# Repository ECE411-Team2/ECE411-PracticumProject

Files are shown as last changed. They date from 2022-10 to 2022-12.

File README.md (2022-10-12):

# ECE-411-Team-2

Our project planning will be split into practium checkpoints, each with their own focus:
  1. Teams Formed 
  2. Projects Decided 
  3. Project requirements (Product Design Specification - PDS)
  4. Preliminary schematic
  5. Final schematic + preliminary layout
  6. Boards to manufacturing (actual final schematic + final layout)
  7. Demonstrations

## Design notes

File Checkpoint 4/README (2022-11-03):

Checkpoint Outcomes 

By week 5-6
  - First bits of code
  - Parts ordered 
  - Preliminary schematic

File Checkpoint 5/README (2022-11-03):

Checkpoint Outcomes 

By week 6-7
  - Final schematic 
  - Preliminary layout / CAD
  - Most code implemented and prototyped 
  - Project Schedule
  - BOM

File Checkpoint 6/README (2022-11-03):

Checkpoint Outcomes

By week 8: 
  - Design Review 
  - Final Layout/ CAD
  - Send items to EPL for print
  
By week 9: 
  - Assembled board 
  - Tested board
  - Programmed board

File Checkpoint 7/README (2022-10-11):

Checkpoint Outcomes

By week 10:
  - DEMO!
  
Deliverables for Prof
  - Final presentation/ demo 
  - Colab site 
  - CAD and source files 
  - BOM w/ cost

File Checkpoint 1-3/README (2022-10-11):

Checkpoint Outcomes
 
By week 3 
  - Brainstorm 3 project ideas
  - Create collaboration site 
  - Choose tools for communication, coding, schematic layouts, etc. 

By week 4
  - Project requirments (PDS)
  - Block Diagrams 
  - Rough schematics
  - Inital component research 
  - Inital timeline

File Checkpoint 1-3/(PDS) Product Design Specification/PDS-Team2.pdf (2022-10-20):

Practicum Project: Team 2

ECE 411

10/20/22

Project Description Specification

Executive Summary / Concept of Operations

Our device is a calculator that has the basic functions of addition, subtraction, multiplication, and division. It will be able to do these calculations through binary and decimal and hexadecimal. With our kind of classes in computer engineering, we do a lot of work with binary and hexadecimal, so we can use it in our classes. In order to use it, you will use the buttons, and depending on the setting, will need to type it in binary, decimal, or hexadecimal. From there, you hit the equals button and it will output onto the screen the answer.

Brief Market Analysis

We want to target customers that have a need for doing binary, decimal, and hexadecimal calculations. This target group includes, but is not limited to, computer engineering professionals and students. The other products are calculators such as the TI-30XIIS, but how our calculator differs is that it comes with the ability to do basic calculations in hex and binary. Compared to the price of the TI-30XIIS, which on amazon is listed as 13 USD, we can estimate ours to be around 15-20 USD. This can be accredited to our inexpensive processor and other electronic components. We would see our 3D printed parts costing the most.

Requirements

Our calculator must have keys that will reflect the following: integers 0-9, the 4 basic operators, equals to, negative, clear all, on/off, A-F, and a button to alternate between Binary, Hex, and Decimal. The calculator must have the ability to remember the past result, must have a display, must have a delay of less than 1 second after each key press, and must be portable. We would also like to incorporate other functions that a standard calculator has as well. Such as, our calculator should be able to handle decimals and parentheses. Then, we will have a stretch goal for our calculator device that may include exponents, trig calculations, and constants (i.e pi and e).

System Architecture

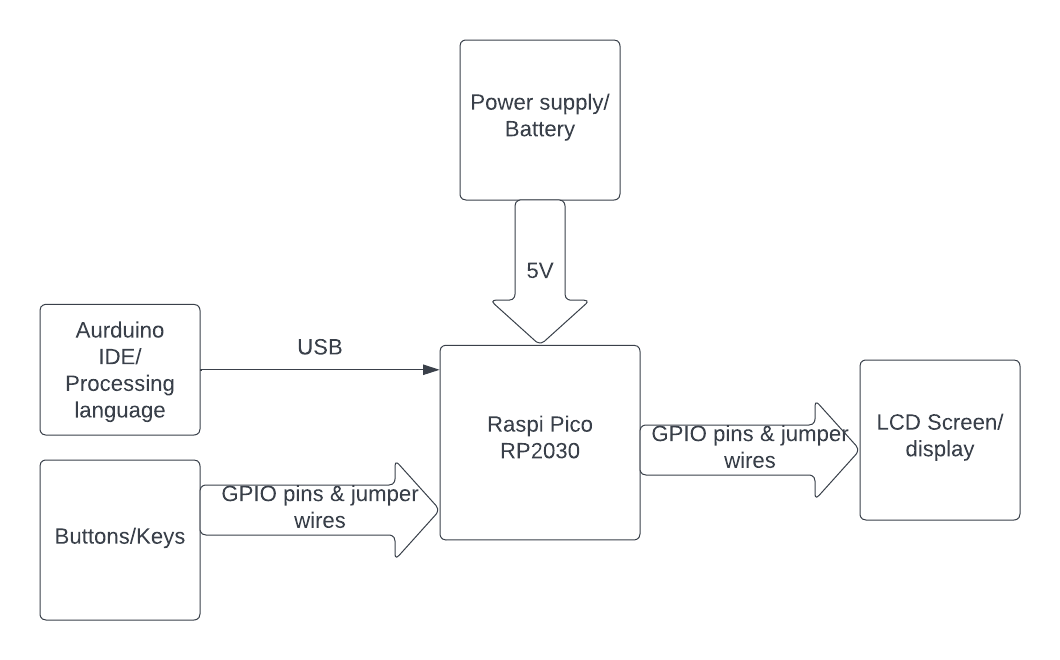
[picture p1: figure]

Design Specification

Sensor:

- Push buttons for each respective key

Processor:

- Raspberry Pi Pico RP2040

Actuator:

- LCD screen

Power:

- 5 Volt battery

Mechanical Design:

- 3D-printed keys for each button
- 3D printed enclosure w/ cutout for LCD screen

Firmware:

- UF2 Bootloader
- Processing language

Development Environment:

- Arduino IDE

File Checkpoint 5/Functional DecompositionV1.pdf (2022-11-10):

Calculator: Level 0

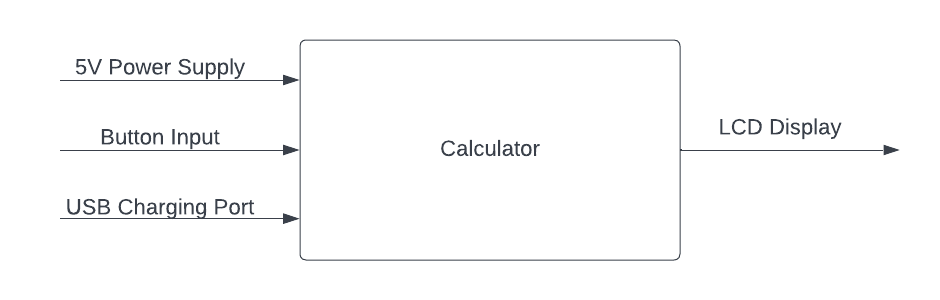
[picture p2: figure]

Module | Calculator
Inputs | Power: 5V DC Button Inputs: Variable Charging Port: USB 5V DC
Outputs | LCD Display: Variable
Functionality | Take input of a mathematical expression and produce a precise calculation. Button input should have user control. LCD display should output the correct calculation to show the user. The calculator can perform basic operations on decimal, hex, and binary numbers.

Calculator: Level 1

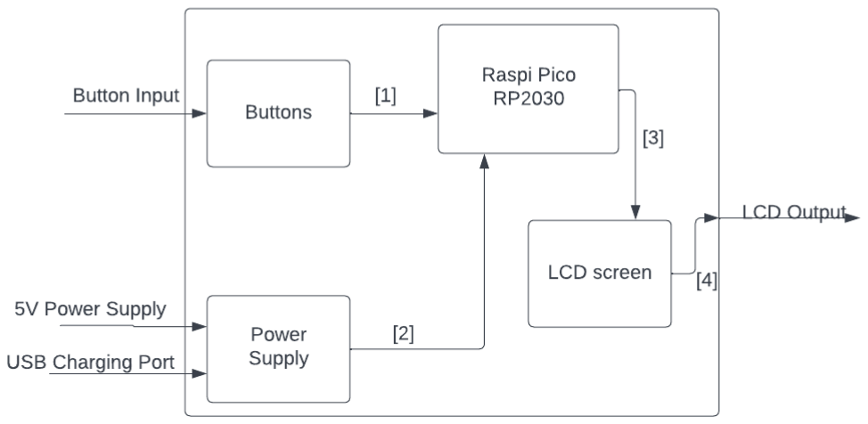
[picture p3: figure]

[1]: GPIO pins
[2]: 5V to power Raspi Pico [3]: I2C data
[4]: LCD Display for user

Raspi Pico RP2030: Level 1

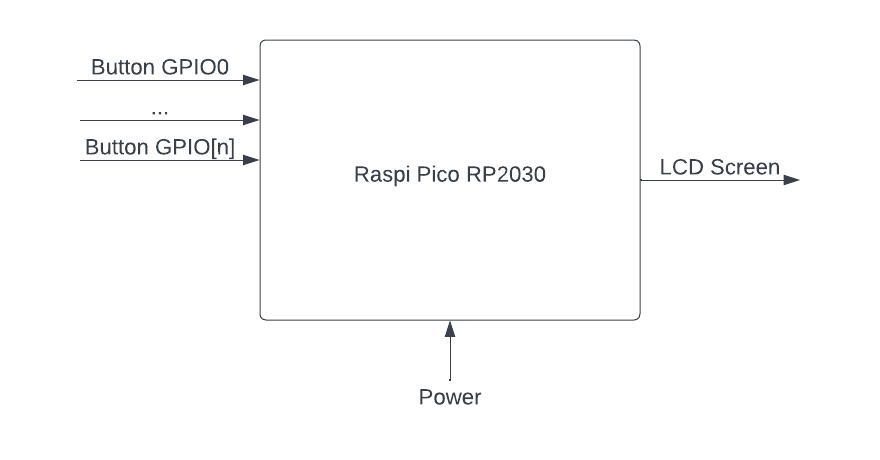
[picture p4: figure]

Module | Raspi Pico RP2030
Inputs | Button GPIO[n] Pins: Tracks I2C data coming in from each button push. Power: 5V supply
Outputs | LCD Screen: I2C data is sent to the LCD screen for display output. The LCD screen is also powered by the Raspi Pico.
Functionality | The Raspi Pico RP2030 serves as the brain of the calculator, processing all incoming information and sending it out to be displayed.

Buttons: Level 1

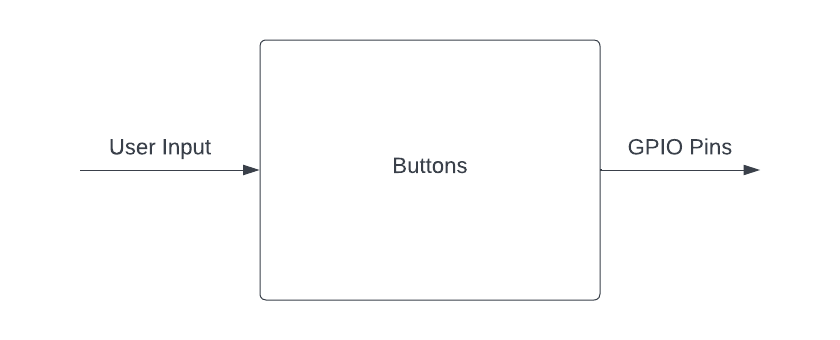
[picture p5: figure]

Module | 25 Buttons
Inputs | User Input: 25 buttons in a 5x5 array, each representing a number, mathematical operation, or turning the device off.
Outputs | GPIO Pins: Connecting to Raspi Pico input pins for processing. Resistors: Each row/column will connect to a ohm resistor (10 total).
Functionality | The user can press any button to input the desired mathematical expression. This will be read and processed by the Raspi Pico.

LCD Screen: Level 1

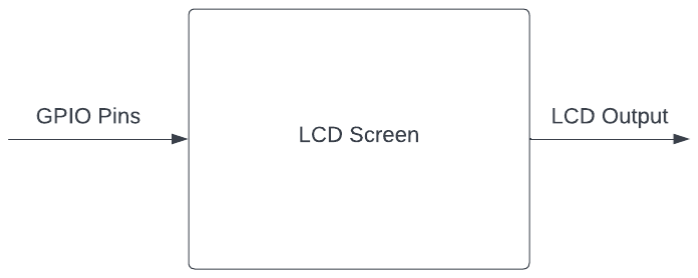
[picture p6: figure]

Module | LCD Screen
Inputs | GPIO Pins: I2C data from the Raspi Pico.
Outputs | LCD Output: LCD display showing the precise calculation of the User’s desired input operation.
Functionality | Will display the information/calculation processed by the Raspi Pico for the user to see.

Power Supply: Level 1

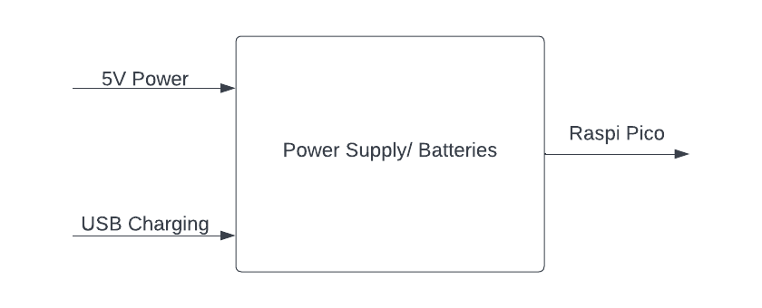
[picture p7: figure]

Module | Power Supply
Inputs | Power: 5V USB Charging: Charge the batteries through a USB input.
Outputs | Raspi Pico: Will supply the Raspi Pico with 5V for necessary function.
Functionality | Supplying the Raspi Pico with DC voltage through a chargeable battery.

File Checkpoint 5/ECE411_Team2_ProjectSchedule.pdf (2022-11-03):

Name | Begin date | End date | Duration
1: Initial Prototype | 10/19/22 | 10/31/22 | 9
1.1 Block diagram | 10/19/22 | 10/20/22 | 2
1.2: Prelim Schematic | 10/20/22 | 10/24/22 | 3
1.3: Prelim Board Layout | 10/25/22 | 10/27/22 | 3
1.4: Skeloton/Prelim Code | 10/26/22 | 10/31/22 | 4
2: CAD Rough Draft | 11/1/22 | 11/16/22 | 12
2.1: Housing Design | 11/1/22 | 11/4/22 | 4
2.2: BOM | 11/3/22 | 11/4/22 | 2
2.3: Final Button Circuitry | 11/4/22 | 11/16/22 | 9
3: Integration and Testing | 11/11/22 | 11/29/22 | 13
3.1: Final Code | 11/11/22 | 11/18/22 | 6
3.2: Print Off Housing and Board | 11/11/22 | 11/21/22 | 7
3.3: Put circuitry In Housing | 11/22/22 | 11/25/22 | 4
3.4: Debugging | 11/11/22 | 11/29/22 | 13
4: Demo Prep | 11/30/22 | 12/9/22 | 8
4.1: Test Plan | 11/30/22 | 12/1/22 | 2
4.2: Presentation and Report Prep | 12/1/22 | 12/8/22 | 6
4.3: Demo | 12/9/22 | 12/9/22 | 1
ECE411 - Team2 Practicum | Nov 2, 2022
Tasks | 2

ECE411 - Team2 Practicum | Nov 2, 2022
Gantt Chart | 3
Name | Begin date | End date | Duration
1: Initial Prototype | 10/19/22 | 10/31/22 | 9.0 day
1.1 Block diagram | 10/19/22 | 10/20/22 | 2.0 day
1.2: Prelim Schematic | 10/20/22 | 10/24/22 | 3.0 day
1.3: Prelim Board Layout | 10/25/22 | 10/27/22 | 3.0 day
1.4: Skeloton/Prelim Code | 10/26/22 | 10/31/22 | 4.0 day
2: CAD Rough Draft | 11/1/22 | 11/16/22 | 12.0 day
2.1: Housing Design | 11/1/22 | 11/4/22 | 4.0 day
2.2: BOM | 11/3/22 | 11/4/22 | 2.0 day
2.3: Final Button Circuitry | 11/4/22 | 11/16/22 | 9.0 day
3: Integration and Testing | 11/11/22 | 11/29/22 | 13.0 day
3.1: Final Code | 11/11/22 | 11/18/22 | 6.0 day
3.2: Print Off Housing and Board | 11/11/22 | 11/21/22 | 7.0 day
3.3: Put circuitry In Housing | 11/22/22 | 11/25/22 | 4.0 day
3.4: Debugging | 11/11/22 | 11/29/22 | 13.0 day
4: Demo Prep | 11/30/22 | 12/9/22 | 8.0 day
4.1: Test Plan | 11/30/22 | 12/1/22 | 2.0 day
4.2: Presentation and Report Prep | 12/1/22 | 12/8/22 | 6.0 day
4.3: Demo | 12/9/22 | 12/9/22 | 1.0 day
October 2022 | November 2022 | December 2022
19 | 20 | 21 | 24 | 25 | 26 | 27 | 28 | 31 | 1 | 2 | 3 | 4 | 7 | 8 | 9 | 10 | 11 | 14 | 15 | 16 | 17 | 18 | 21 | 22 | 23 | 24 | 25 | 28 | 29 | 30 | 1 | 2 | 5 | 6 | 7 | 8

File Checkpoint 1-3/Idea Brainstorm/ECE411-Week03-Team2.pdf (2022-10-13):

Team 2
ECE 411
10/12/22 Week 3
- Photoresistor Car
- Sensor: Photoresistor,
- Actuator: Motor/s
- Processor: Arduino
- Links:
https://www.sciencebuddies.org/science-fair-projects/project-ideas/Robotics_p022/robotics/light-following-robot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 (https://www.sciencebuddies.org/science-fair-projects/project-ideas/Robotics_p022/robotics/light-following-robot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) https://www.instructables.com/Photoresistor-Sensor-With-Arduino-Uno-R3/
A car that will react to a light; driving towards the souce with the help of a couple of photoresistors. There would be 4 motors and an Arduino to power it. However, this would be a little difficult to power as the Arduino can only provide up to 5V.
We desire to do this project as one of our group members mentioned that his brother attempted a similar project during his time in college. With a good foundation brought by that experience, we think this specific take would be attractive yet challenging. The idea of building a car, in itself, is a very fun thing that we think we would find a lot of enjoyment in.
- Calculator (This is what we will go with)
- Sensor: Key/number pad
- Actuator: LCD,
- Processor: Arduino
- Links: https://unimplementedtrap.com/sb116-programmers-calculator Arduino Calculator - Arduino Project Hub (https://create.arduino.cc/projecthub/123samridhgarg/arduino-calculator-bb57c7) This is a traditional calculator with a keypad that allows user input and an LED screen showing the appropriate output. Basic operations would be our first goal but our stretch goal would be to incorporate memory, integrals, and other ways to incorporate complex calculations.
We are very intrigued to see how many features we could add to this. Is it as easy as it seems? As we explore the Arduino library, we want to see how much we can incorporate our own unique spin on a tool that many use on a daily basis.

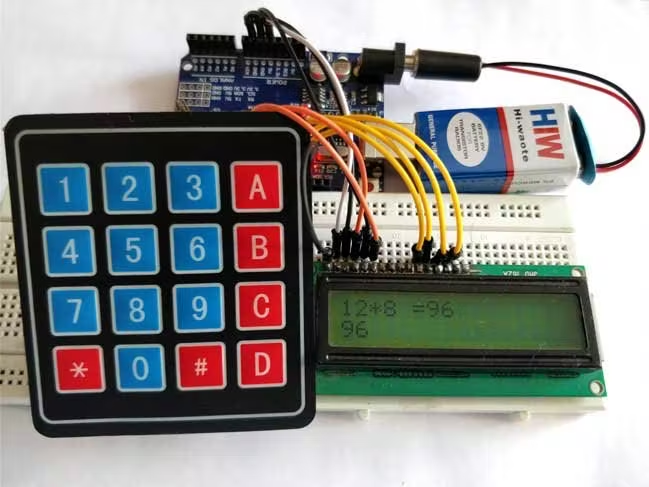
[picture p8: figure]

- Heartbeat sensor
- Sensor: Pulse sensor, potentiometer
- Actuator: LCD, LED
- Processor: Arduino
- Links: Heartbeat Sensor using Arduino (Heart Rate Monitor) (electronicshub.org) (https://www.electronicshub.org/heartbeat-sensor-using-arduino-heart-rate-monitor/) https://create.arduino.cc/projecthub/Ingeimaks/diy-heart-rate-sensor-a96e 89 (https://create.arduino.cc/projecthub/Ingeimaks/diy-heart-rate-sensor-a96e89)
Heart Beat Monitoring Device - Arduino Project Hub (https://create.arduino.cc/projecthub/mohammadsohail0008/heart-beat-monitoring-device-8adf7c)
This device will have a pulse sensor that the user will place their finger on to monitor their heartbeat. The LCD will then display BPM of their heart rate with accuracy. There will be an LED that will turn on, signaling it is reading user input.
This seems to be a very increasing yet difficult project. When researching ideas, we noticed how many people attempt this but there were varying levels of success. There were a lot of issues with accuracy. We are curious to see how accurate we could get this device.

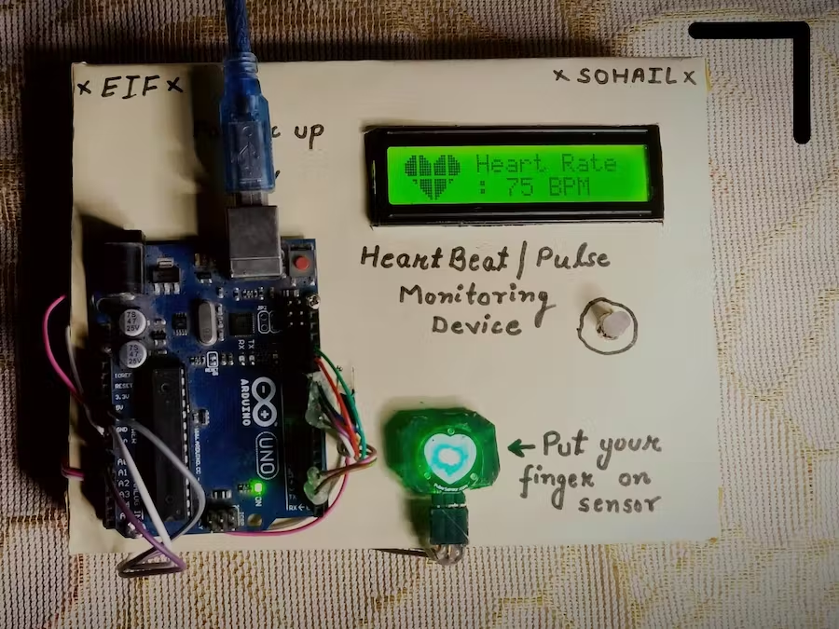
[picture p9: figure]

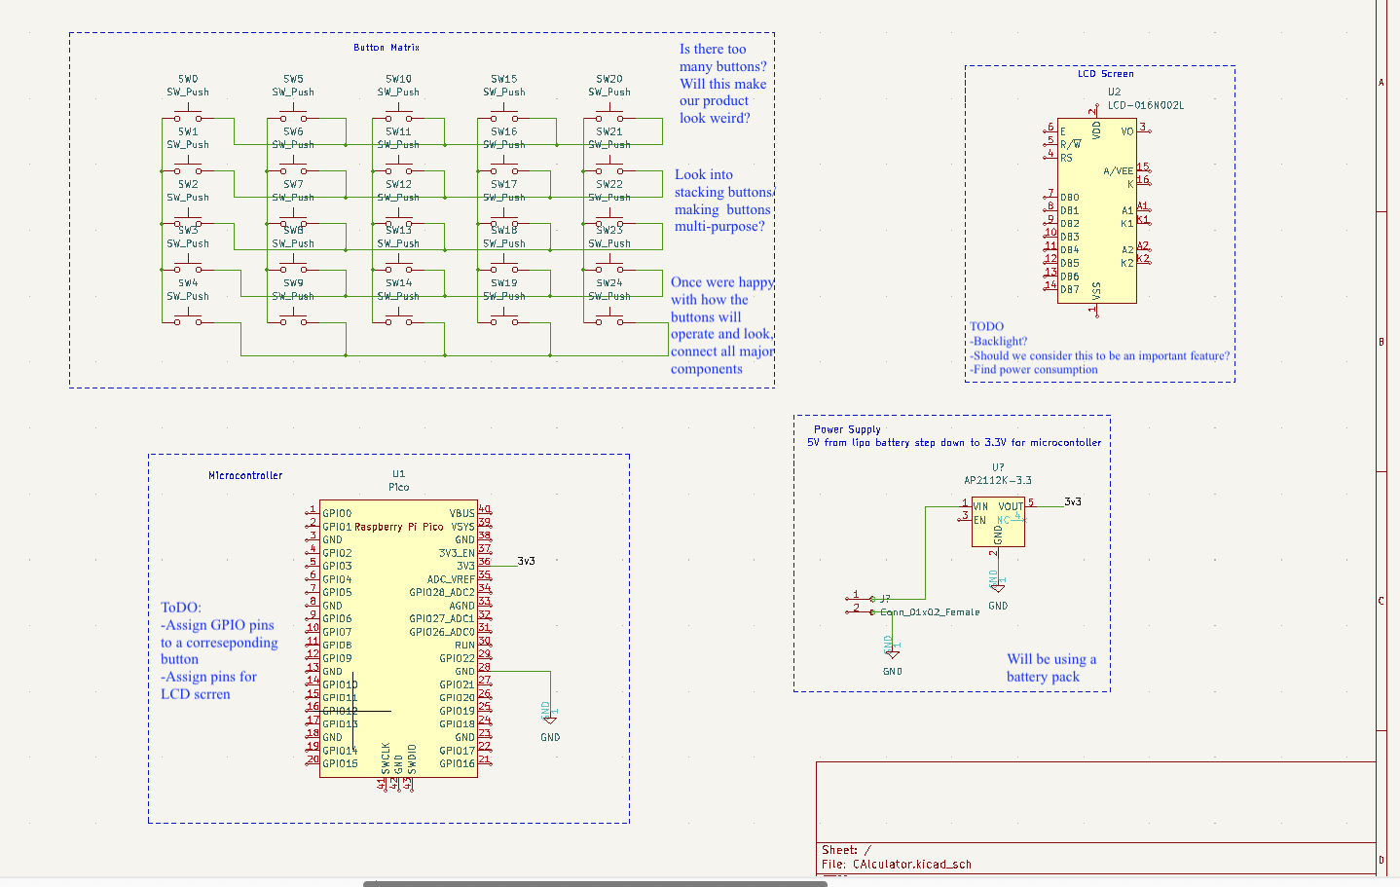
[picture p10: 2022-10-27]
Checkpoint 4/Preliminary Schematic/Calculator.png

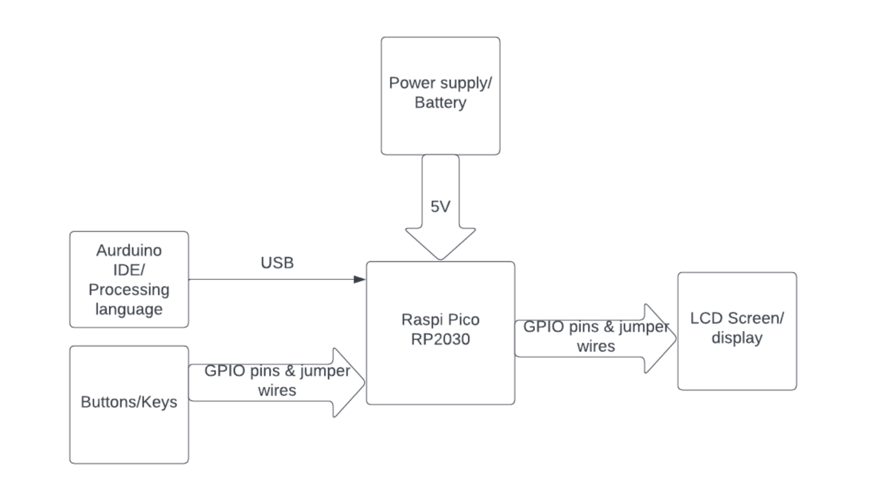
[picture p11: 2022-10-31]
Checkpoint 1-3/Block Diagram 1/Team2_BlockDiagram.png

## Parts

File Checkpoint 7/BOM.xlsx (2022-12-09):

Bill Of Materials for: [TEAM 2]
Last modified: [2022-12-01]
PCB version: [PCB VERSION #2]
BOM revision: [BOM REVISION #2] |  | P/NP | Place/Not Place (components marked NP are not stuffed on the board)
Cnt | Part References | P/NP | Mfg | Mfg PN | Description | Dist | Dist Part Number | Cost Ea. | Cost Total
75 | SW0 to SW24 | P | Chanzon | RA11-BUTTON-SWITCH | Tact Push Button Switch 6x6x 6mm Micro Momentary Tact Switch Terminal Length 3.5mm 2 pin | Amazon | B09R3ZPWJ7 | $0.30 | $22.50
2 | U2 | P | GeeekPi | LCM1602A--SDBTSW-5APWUC | I2C 1602 LCD Display Module 16X2 Character Serial Blue Backlight LCD | Amazon | B07S7PJYM6 | $10.99 | $21.98
4 | U3 | P | MakerFocus | A-9065115 | 4pcs 3.7V Lithium Rechargable Battery JST1.25 Connector 2pin, 852540 3.7V | Amazon | B07CXNQ3ZR | $5.25 | $20.99
4 | U1 | P | Generic | 0C-13694V-0H3320 | Raspberry Pi Pico RP2040 microcontroller | Amazon | B09437S9X4 | $5.50 | $22.21
40 | R1-R10 | P | N/A | N/A | 330Ohm 1/16W, 5% Resistors | EPL | 1206 | $0.04 | $1.60
4 | U0 | NP | Oshpark | N/A | Custom PCB Board | EPL | N/A | $20.57 | $82.30
1 | U4 | NP | Craft Smart | 694300 | Red Silicone Craft Mat | MSPCI | 10694300 | $5.24 | $5.24
1 | U5 | NP | N/A | N/A | Custom 3D Printed Model | EPL | N/A | $7.00 | $7.00
 |  |  |  |  |  |  |  | TOTAL: | $183.82
VERSION INFO
Rev | Date | Notes
1.0r0 | 2022-11-07 | Initial BOM. Not everything chosen yet
2.0r0 | 2022-12-01 | Final BOM

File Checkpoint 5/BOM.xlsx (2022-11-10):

Bill Of Materials for: [TEAM 2]
Last modified: [2022-11-07]
PCB version: [PCB VERSION #1]
BOM revision: [BOM REVISION #1] |  | P/NP | Place/Not Place (components marked NP are not stuffed on the board)
Cnt | Part References | P/NP | Mfg | Mfg PN | Description | Dist | Dist Part Number | Cost Ea. | Cost Total
25 | SW0 to SW24 | P | Chanzon | RA11-BUTTON-SWITCH | Tact Push Button Switch 6x6x 6mm Micro Momentary Tact Switch Terminal Length 3.5mm 2 pin | Amazon | B09R3ZPWJ7 | $0.30 | $6.99
1 | U2 | P | GeeekPi | LCM1602A--SDBTSW-5APWUC | I2C 1602 LCD Display Module 16X2 Character Serial Blue Backlight LCD | Amazon | B07S7PJYM6 | $10.99 | $10.99
4 | U3 | P | MakerFocus | A-9065115 | 4pcs 3.7V Lithium Rechargable Battery JST1.25 Connector 2pin, 852540 3.7V | Amazon | B07CXNQ3ZR | $5.25 | $20.99
4 | U1 | P | Generic | 0C-13694V-0H3320 | Raspberry Pi Pico RP2040 microcontroller | Amazon | B09437S9X4 | $5.50 | $22.21
5 | N/A | NP | N/A | N/A | resistors | N/A | N/A | $0.00 | $0.00
 |  |  |  |  |  |  |  | TOTAL: | $60.02
VERSION INFO
Rev | Date | Notes
1.0r0 | 2020-11-07 | Initial BOM. Not everything chosen yet

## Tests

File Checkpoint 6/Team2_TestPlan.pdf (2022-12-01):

Test Author: Team 2 - Ahliah, Angelo, Bendjy, Ibrahim
Test Case Name: | LCD Display 1 Test | Test ID #: | LCD-01
Description: | Verify the button inputs work by displaying appropriate button inputs. Each button has a number or action associated with it so, when a button is pushed, the corresponding number/action must be displayed on the LCD screen. | Type: | □ white box ✔ black box □ ________

Tester Information
| Name of Tester: | | Date:
| HW/SW Version: | 1.0 | Time:
| Setup: | Verify overall wiring reflects the schematic and LCD screen is OFF, nothing on the screen should be displayed but it must be tied to power.
S T E P | Action | Expected Result | P A S S | F A I L | N / A | Comments
1 | Press the ‘ON’ button | LCD screen turns ON and is blank
2 | Press the ‘1’ button | 1 appears on the top row of screen
3 | Press the ‘2’ button | 12 appears on the top row of screen
4 | Press the ‘3’ button | 123 appears on the top row of screen
5 | Press the ‘4’ button | 1234 appears on the top row of screen
6 | Press the ‘5’ button | 12345 appears on the top row of screen
7 | Press the ‘6’ button | 123456 appears on the top row of screen
8 | Press the ‘7’ button | 1234567 appears on the top row of screen
9 | Press the ‘8’ button | 12345678 appears on the top row of screen
10 | Press the ‘9’ button | 123456789 appears on the top row of screen
11 | Press the ‘0’ button | 1234567890 appears on the top row of screen
12 | Press the ‘CLR’ button | LCD screen is still ON but blank
13 | Press the ‘OFF’ button | LCD screen turns OFF
| Overall test result:

Test Author: Team 2 - Ahliah, Angelo, Bendji, Ibrahim
Test Case Name: | I2C Communication | Test ID #: | I2C-COM-01
Description: | Verify that the I2C bus is communicating with the LCD. Information must be able to be transmitted through the I2C to the LCD and then accurately displayed on the screen. | Type: | □ white box ✔ black box □ ________

Tester Information
| Name of Tester: | Bendjy Faurestal | Date: | 11/30/2022
| HW/SW Version: | 1.0 | Time: | 8:00pm
| Setup: | Have the LCD screen OFF and tied to power, ground, I2C SDA and I2C SCL.
S T E P | Action | Expected Result | P A S S | F A I L | N / A | Comments
1 | Send ‘on’ signal | LCD screen is powered and turned ON with a clear screen | ✔ | | | The display is blank each time it is powered on.
2 | Send value of ‘1’ | LCD screen displays ‘1’ on the top row | ✔
3 | Send value of ‘2’ | LCD screen displays ‘12’ on the top row | ✔
4 | Send ‘off’ signal | LCD screen turns OFF | ✔
| Overall test result: | | ✔

Test Author: Team 2 - Ahliah, Angelo, Bendji, Ibrahim
Test Case Name: | Mathematical Operations Software Test | Test ID #: | Math-01
Description: | Verify that the math functions work properly and that the correct data is displayed in the console with decimal, binary and hex as a result. | Type: | □ white box ✔ black box □ ________

Tester Information
| Name of Tester: | Angelo Maldonado-Liu | Date: | 11/30/2022
| HW/SW Version: | 1.0 | Time: | 6:30pm
| Setup: | Plug Ras-Pi Pico chip into a computer and open the console.
S T E P | Action | Expected Result | P A S S | F A I L | N / A | Comments
1 | Perform ‘15 + 26’ Math operation, then display result | ‘41’ displayed in console | ✔
2 | Change display from last result (41 decimal) to a hex value | ‘29’ displayed in console | ✔
3 | Change display from last result (29 hex) to binary | ‘101001’ displayed in the console | ✔
4 | Perform ‘14 / 6’ math operation, then display result | ‘2’ is displayed in the console | ✔
5 | Perform ‘3 * 18’ math operation, then display result | ‘54’ is displayed in the console | ✔
6 | Perform ‘31 - 9’ math operation, then display result | ‘22’ is displayed in the console | ✔
| Overall test result: | | ✔ | | | Values displayed the expected results in a forever loop. This was due to a coding error within the standard void loop. Incorporating an end to the loop fixed this issue.

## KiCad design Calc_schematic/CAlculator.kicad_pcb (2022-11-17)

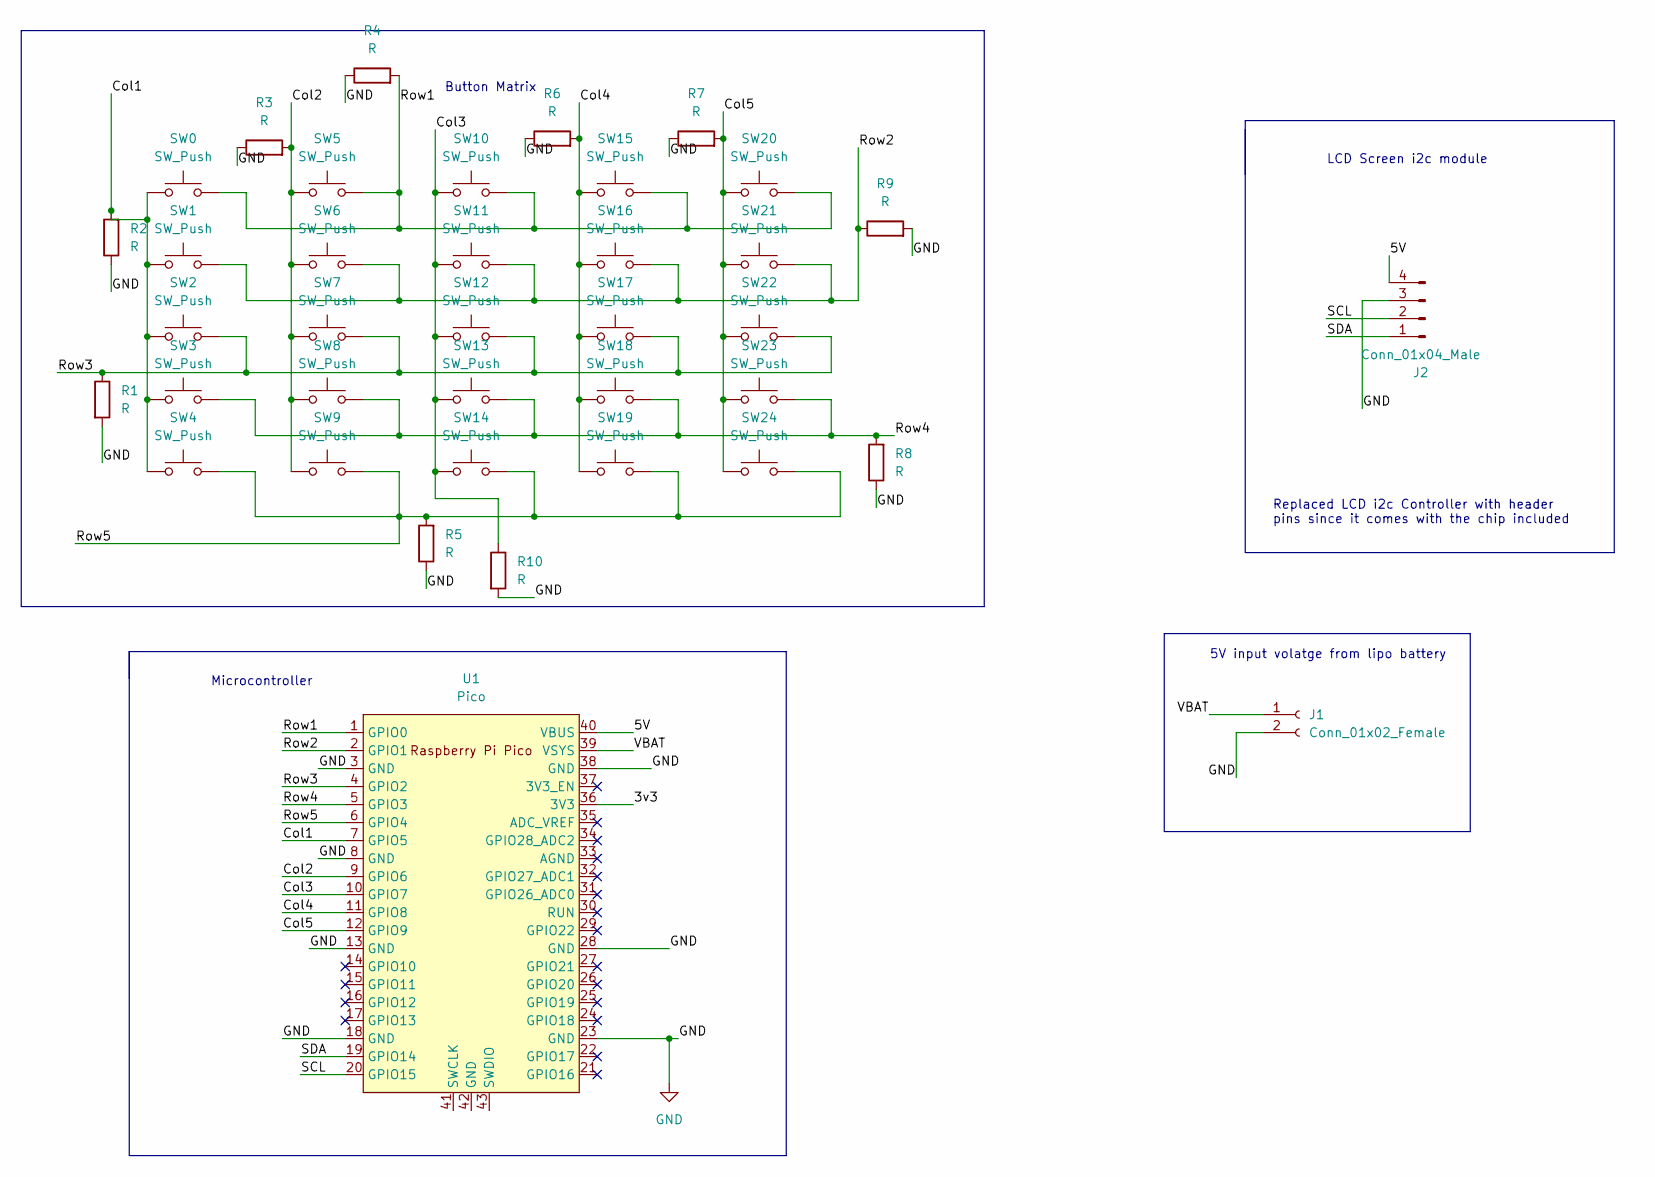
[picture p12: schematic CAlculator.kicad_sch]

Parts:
J1: Conn_01x02_Female; JST_PH_B2B-PH-K_1x02_P2.00mm_Vertical
J2: Conn_01x04_Male; PinHeader_1x04_P2.54mm_Vertical
R1, R2, R3, R4, R5, R6, R7, R8, R9, R10: R; RESC3216X60N
SW0, SW1, SW2, SW3, SW4, SW5, SW6, SW7, SW8, SW9, SW10, SW11, SW12, SW13, SW14, SW15, SW16, SW17, SW18, SW19, SW20, SW21, SW22, SW23, SW24: SW_Push; SW_PUSH_6mm_H5mm
U1: Pico; RPi_Pico_SMD_TH

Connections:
/3v3: U1.36 (3V3)
/5V: J2.4, U1.40 (VBUS)
/Col1: R2.2, SW0.1, SW1.1, SW2.1, SW3.1, SW4.1, U1.7 (GPIO5)
/Col2: R3.2, SW5.1, SW6.1, SW7.1, SW8.1, SW9.1, U1.9 (GPIO6)
/Col3: R10.1, SW10.1, SW11.1, SW12.1, SW13.1, SW14.1, U1.10 (GPIO7)
/Col4: R6.2, SW15.1, SW16.1, SW17.1, SW18.1, SW19.1, U1.11 (GPIO8)
/Col5: R7.2, SW20.1, SW21.1, SW22.1, SW23.1, SW24.1, U1.12 (GPIO9)
/Row1: R4.2, SW0.2, SW5.2, SW10.2, SW15.2, SW20.2, U1.1 (GPIO0)
/Row2: R9.1, SW1.2, SW6.2, SW11.2, SW16.2, SW21.2, U1.2 (GPIO1)
/Row3: R1.1, SW2.2, SW7.2, SW12.2, SW17.2, SW22.2, U1.4 (GPIO2)
/Row4: R8.2, SW3.2, SW8.2, SW13.2, SW18.2, SW23.2, U1.5 (GPIO3)
/Row5: R5.2, SW4.2, SW9.2, SW14.2, SW19.2, SW24.2, U1.6 (GPIO4)
/SCL: J2.2, U1.20 (GPIO15)
/SDA: J2.1, U1.19 (GPIO14)
/VBAT: J1.1, U1.39 (VSYS)
GND: J1.2, J2.3, R1.2, R2.1, R3.1, R4.1, R5.1, R6.1, R7.1, R8.1, R9.2, R10.2, U1.3 (GND), U1.8 (GND), U1.13 (GND), U1.18 (GND), U1.23 (GND), U1.28 (GND), U1.38 (GND)

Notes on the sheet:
LCD Screen i2c module
5V input volatge from lipo battery
Microcontroller
Replaced LCD i2c Controller with header pins since it comes with the chip included
Button Matrix

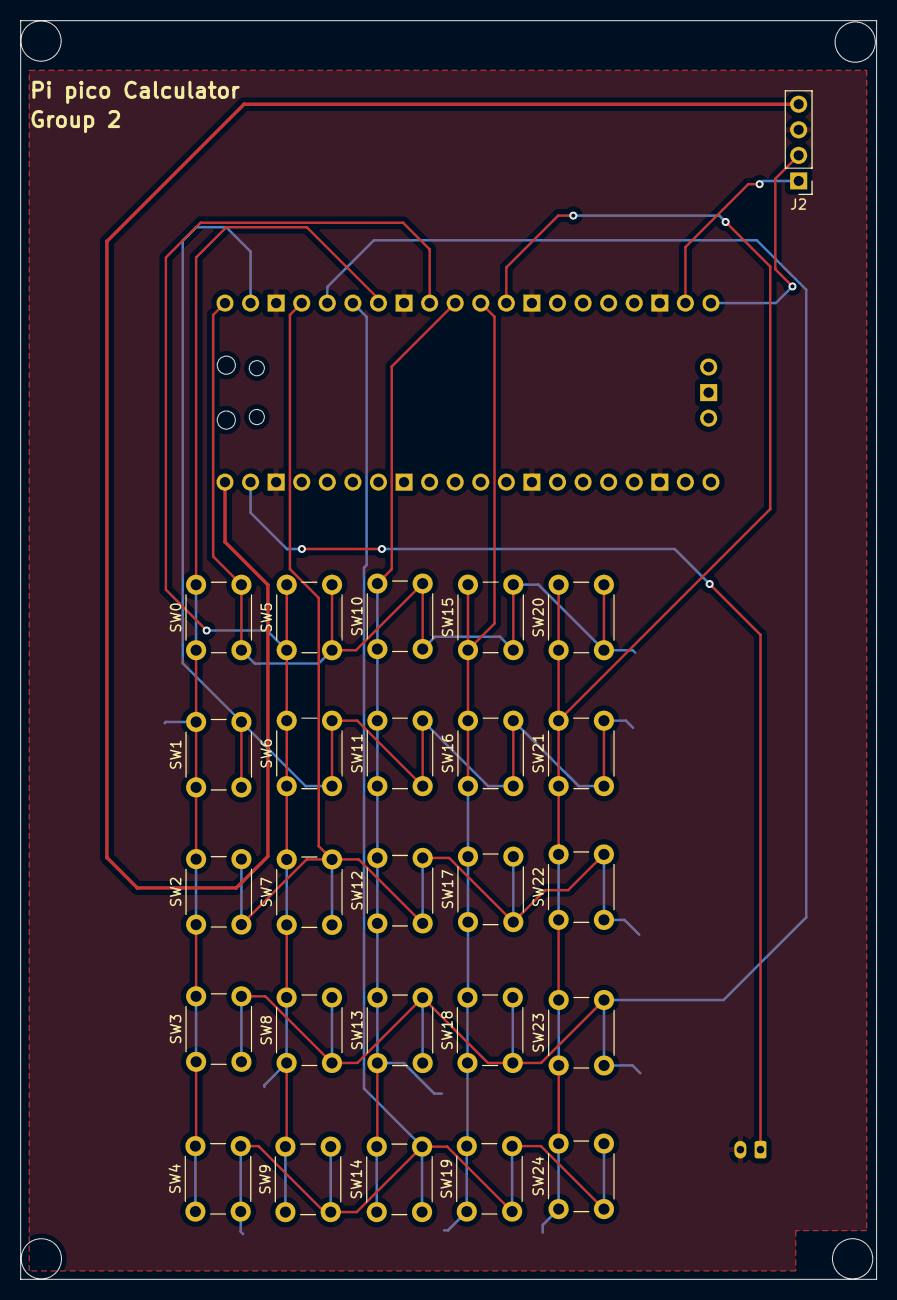
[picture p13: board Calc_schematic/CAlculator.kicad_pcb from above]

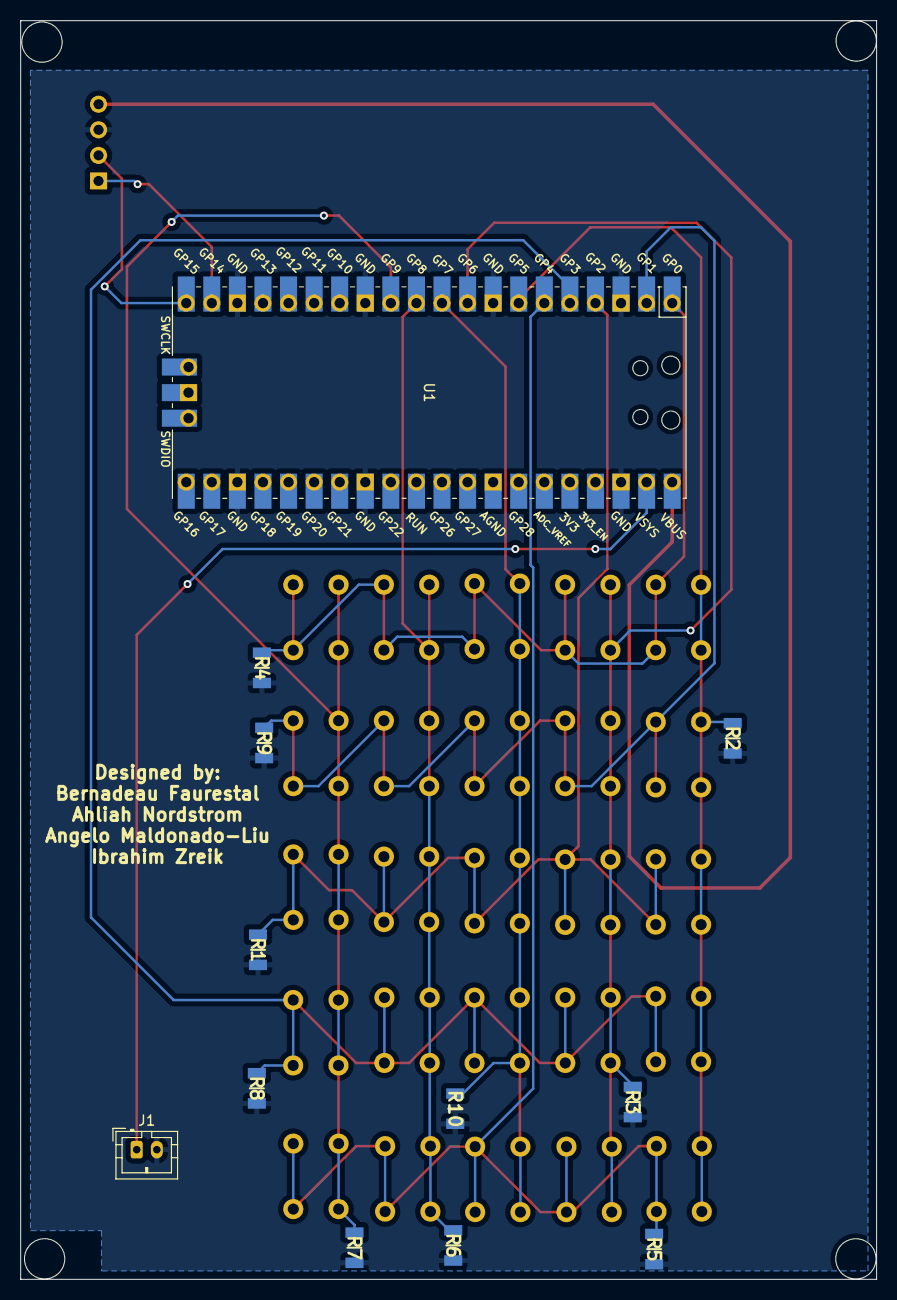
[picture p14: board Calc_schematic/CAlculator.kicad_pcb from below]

Board: 2 copper layers, 85.0 x 125.0 mm, 38 parts (12 on the bottom side), 15 nets.

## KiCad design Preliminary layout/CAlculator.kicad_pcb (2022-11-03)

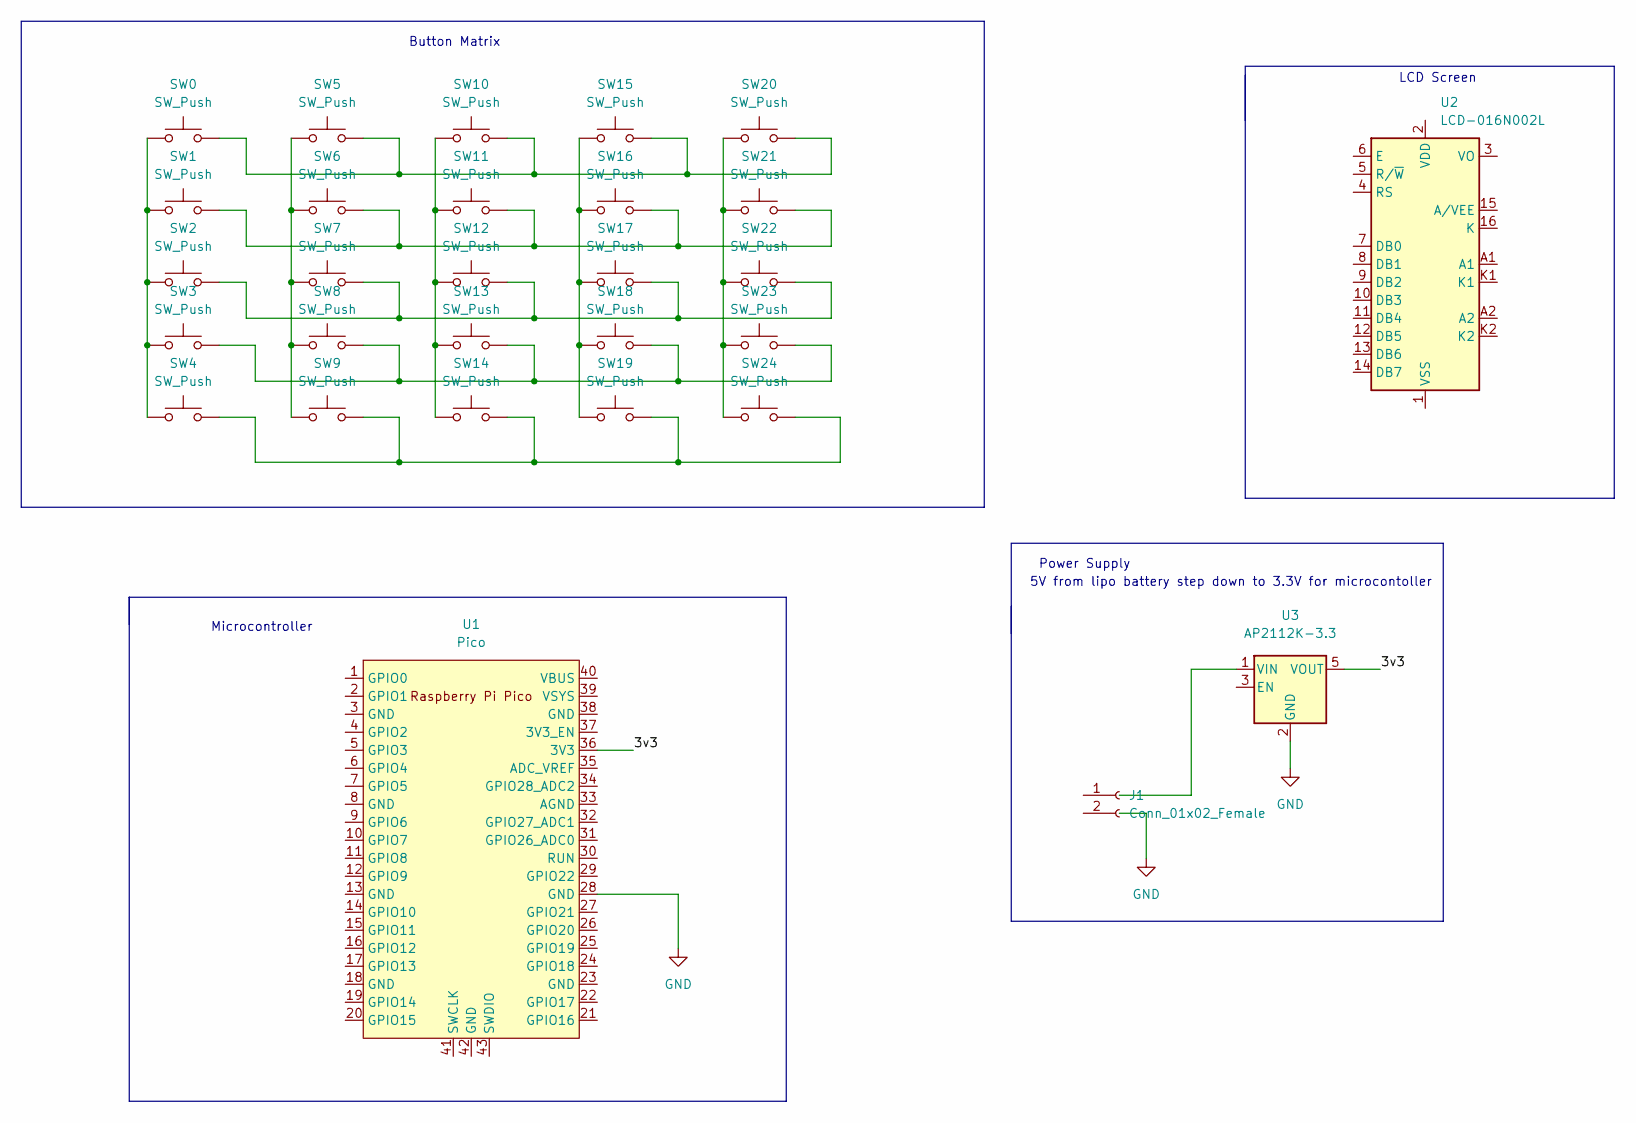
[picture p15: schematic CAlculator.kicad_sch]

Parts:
J1: Conn_01x02_Female; JST_PH_B2B-PH-K_1x02_P2.00mm_Vertical
SW0, SW1, SW2, SW3, SW4, SW5, SW6, SW7, SW8, SW9, SW10, SW11, SW12, SW13, SW14, SW15, SW16, SW17, SW18, SW19, SW20, SW21, SW22, SW23, SW24: SW_Push; Panasonic_EVQPUK_EVQPUB
U1: Pico; RPi_Pico_SMD_TH
U2: LCD-016N002L
U3: AP2112K-3.3; SOT-23-5

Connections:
/3v3: U1.36 (3V3), U3.5 (VOUT)
GND: U1.28 (GND), U3.2 (GND)
unnamed: SW0.1, SW1.1, SW2.1, SW3.1, SW4.1
unnamed: SW0.2, SW5.2, SW10.2, SW15.2, SW20.2
unnamed: SW1.2, SW6.2, SW11.2, SW16.2, SW21.2
unnamed: SW5.1, SW6.1, SW7.1, SW8.1, SW9.1
unnamed: SW10.1, SW11.1, SW12.1, SW13.1, SW14.1
unnamed: SW2.2, SW7.2, SW12.2, SW17.2, SW22.2
unnamed: SW3.2, SW8.2, SW13.2, SW18.2, SW23.2
unnamed: SW4.2, SW9.2, SW14.2, SW19.2, SW24.2
unnamed: SW15.1, SW16.1, SW17.1, SW18.1, SW19.1
unnamed: SW20.1, SW21.1, SW22.1, SW23.1, SW24.1

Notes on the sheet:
LCD Screen
5V from lipo battery step down to 3.3V for microcontoller
Power Supply
Microcontroller
Button Matrix

Board: 2 copper layers, 28 parts (0 on the bottom side), 10 nets, no tracks yet.

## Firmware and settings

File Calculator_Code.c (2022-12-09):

/**
 * Copyright (c) 2020 Raspberry Pi (Trading) Ltd.
 *
 * SPDX-License-Identifier: BSD-3-Clause
 */

#include <stdio.h>
#include <string.h>
#include <math.h>
#include "pico/stdlib.h"
#include "hardware/i2c.h"
#include "pico/binary_info.h"
#include "hardware/gpio.h"		//https://raspberrypi.github.io/pico-sdk-doxygen/gpio_8h.html



#define PICO_DEFAULT_LED_PIN 25

//Changing I2C default pins to GP14 and GP15
#define PICO_DEFAULT_I2C 1
#define PICO_DEFAULT_I2C_SDA_PIN 14
#define PICO_DEFAULT_I2C_SCL_PIN 15
#define i2c_default i2c1


/* Example code to drive a 16x2 LCD panel via a I2C bridge chip (e.g. PCF8574)

   NOTE: The panel must be capable of being driven at 3.3v NOT 5v. The Pico
   GPIO (and therefor I2C) cannot be used at 5v.

   You will need to use a level shifter on the I2C lines if you want to run the
   board at 5v.

   Connections on Raspberry Pi Pico board, other boards may vary.

   GPIO 4 (pin 6)-> SDA on LCD bridge board
   GPIO 5 (pin 7)-> SCL on LCD bridge board
   3.3v (pin 36) -> VCC on LCD bridge board
   GND (pin 38)  -> GND on LCD bridge board
*/
// commands
const int LCD_CLEARDISPLAY = 0x01;
const int LCD_RETURNHOME = 0x02;
const int LCD_ENTRYMODESET = 0x04;
const int LCD_DISPLAYCONTROL = 0x08;
const int LCD_CURSORSHIFT = 0x10;
const int LCD_FUNCTIONSET = 0x20;
const int LCD_SETCGRAMADDR = 0x40;
const int LCD_SETDDRAMADDR = 0x80;

// flags for display entry mode
const int LCD_ENTRYSHIFTINCREMENT = 0x01;
const int LCD_ENTRYLEFT = 0x02;

// flags for display and cursor control
const int LCD_BLINKON = 0x01;
const int LCD_CURSORON = 0x02;
const int LCD_DISPLAYON = 0x04;

// flags for display and cursor shift
const int LCD_MOVERIGHT = 0x04;
const int LCD_DISPLAYMOVE = 0x08;

// flags for function set
const int LCD_5x10DOTS = 0x04;
const int LCD_2LINE = 0x08;
const int LCD_8BITMODE = 0x10;

// flag for backlight control
const int LCD_BACKLIGHT = 0x08;

const int LCD_ENABLE_BIT = 0x04;

// By default these LCD display drivers are on bus address 0x27
static int addr = 0x27;


//integers for button array
int row1 = 0;
int row2 = 1;
int row3 = 2;
int row4 = 3;
int row5 = 4;

int col1 = 5;
int col2 = 6;
int col3 = 7;
int col4 = 8;
int col5 = 9;

int haveinput;
int currentvalue0 = 0;
int currentvalue1 = 0;
int resultvalue = 0;

char msg[10] ;
    


char operation = '0';
int valuenumber = 0;
char value0[14];
char value1[14];
char result[16];
char result1[16];
// 0 for decimal, 1 for binary, 2 for hex
int numtype = 0;

int numinputs = 0;

int temp; //this is for hex to ascii

int lcdstate = 0; //this is the state of on or off for the lcd

//testing
const uint LED_PIN = PICO_DEFAULT_LED_PIN;
//gpio_init(LED_PIN);
//gpio_set_dir(LED_PIN, GPIO_OUT);


// Modes for lcd_send_byte
#define LCD_CHARACTER  1
#define LCD_COMMAND    0

#define MAX_LINES      2
#define MAX_CHARS      16

/* Quick helper function for single byte transfers */
void i2c_write_byte(uint8_t val) {
#ifdef i2c_default
    i2c_write_blocking(i2c_default, addr, &val, 1, false);
#endif
}

void lcd_toggle_enable(uint8_t val) {
    // Toggle enable pin on LCD display
    // We cannot do this too quickly or things don't work
#define DELAY_US 600
    sleep_us(DELAY_US);
    i2c_write_byte(val | LCD_ENABLE_BIT);
    sleep_us(DELAY_US);
    i2c_write_byte(val & ~LCD_ENABLE_BIT);
    sleep_us(DELAY_US);
}

// The display is sent a byte as two separate nibble transfers
void lcd_send_byte(uint8_t val, int mode) {
    uint8_t high = mode | (val & 0xF0) | LCD_BACKLIGHT;
    uint8_t low = mode | ((val << 4) & 0xF0) | LCD_BACKLIGHT;

    i2c_write_byte(high);
    lcd_toggle_enable(high);
    i2c_write_byte(low);
    lcd_toggle_enable(low);
}

void lcd_clear(void) {
    lcd_send_byte(LCD_CLEARDISPLAY, LCD_COMMAND);
}

// go to location on LCD
void lcd_set_cursor(int line, int position) {
    int val = (line == 0) ? 0x80 + position : 0xC0 + position;
    lcd_send_byte(val, LCD_COMMAND);
}

static void inline lcd_char(char val) {
    lcd_send_byte(val, LCD_CHARACTER);
}

void lcd_string(const char *s) {
    while (*s) {
        lcd_char(*s++);
    }
}

void lcd_init() {
    lcd_send_byte(0x03, LCD_COMMAND);
    lcd_send_byte(0x03, LCD_COMMAND);
    lcd_send_byte(0x03, LCD_COMMAND);
    lcd_send_byte(0x02, LCD_COMMAND);

    lcd_send_byte(LCD_ENTRYMODESET | LCD_ENTRYLEFT, LCD_COMMAND);
    lcd_send_byte(LCD_FUNCTIONSET | LCD_2LINE, LCD_COMMAND);
    lcd_send_byte(LCD_DISPLAYCONTROL | LCD_DISPLAYON, LCD_COMMAND);
    lcd_clear();
}

//Calculator code start


void switchIO()
{
	gpio_put(row1, false);
	gpio_put(row2, false);
	gpio_put(row3, false);
	gpio_put(row4, false);
	gpio_put(row5, false);
	
	gpio_set_dir(row1, false);
	gpio_set_dir(row2, false);
	gpio_set_dir(row3, false);
	gpio_set_dir(row4, false);
	gpio_set_dir(row5, false);
	
	
	gpio_set_dir(col1, true);
	gpio_set_dir(col2, true);
	gpio_set_dir(col3, true);
	gpio_set_dir(col4, true);
	gpio_set_dir(col5, true);
	
	gpio_put(col1, true);
	gpio_put(col2, true);
	gpio_put(col3, true);
	gpio_put(col4, true);
	gpio_put(col5, true);
	
	return;
}

void domath()
{
    resultvalue = 0;
	if(operation == '+')
	{
		resultvalue = currentvalue0 + currentvalue1;
		numinputs = 0;
		currentvalue0 = 0;
		currentvalue1 = 0;
	}
	
	else if(operation == '-')
	{
		resultvalue = currentvalue0 - currentvalue1;
		numinputs = 0;
		currentvalue0 = 0;
		currentvalue1 = 0;
	}
	
	else if(operation == '*')
	{
		resultvalue = currentvalue0 * currentvalue1;
		numinputs = 0;
		currentvalue0 = 0;
		currentvalue1 = 0;
	}
	
	else if(operation == '/')
	{
		resultvalue = currentvalue0 / currentvalue1;
		numinputs = 0;
		currentvalue0 = 0;
		currentvalue1 = 0;	
	}
	
	valuenumber = 0;
    writetoLCDresult();
	
	return;
}

void writetoLCDresult()
{
    lcd_clear();
    //result = NULL;
	if(numtype == 0)
	{
		itoa(resultvalue, result, 10);
		/*for(int a = 0; a < numinputs; a++)
		{*/

			lcd_string(result);
			sleep_ms(5);

		//}
	}
	
	else if(numtype == 1)
	{
		itoa(resultvalue, result, 2);
		/*for(int a = 0; a < numinputs; a++)
		{*/
        if((int)(ceil(log10(resultvalue)/log10(2)) )> 15)
                {
                    result[(int)ceil(log10(resultvalue)/log10(2))] = '\0';
                }
                else
                {
                    result[15] = '\0';
                }
			lcd_string(result);
			sleep_ms(5);
		//}
	}	
	
	else if(numtype == 2)
	{
		for(int b = numinputs; b < 0; b++)
		{
			temp = resultvalue / (16 ^ b);
			if(temp == 10)
			{
				result[b] = 'A';
			}
			
			else if(temp == 11)
			{
				result[b] = 'B';
			}
			
			else if(temp == 12)
			{
				result[b] = 'C';
			}
			
			else if(temp == 13)
			{
				result[b] = 'D';
			}
			
			else if(temp == 14)
			{
				result[b] = 'E';
			}
			
			else if(temp == 15)
			{
				result[b] = 'F';
			}
		}
			
		/*for(int a = 0; a < numinputs; a++)
		{*/
        if(((int)ceil(log10(resultvalue)/log10(16))) > 15)
                {
                    result[(int)ceil(log10(resultvalue)/log10(16))] = '\0';
                }
                else
                {
                    result[15] = '\0';
                }
			sleep_ms(5);
			lcd_string(result);
		//}
	}
	
	
}

void writetoLCD()
{
    lcd_clear();
    if(valuenumber == 0)
    {
        if(numtype == 0)
        {
            itoa(currentvalue0, result, 10);
            /*for(int a = 0; a < numinputs; a++)
            {*/result[numinputs] = '\0';

                
                lcd_string(value0);
                sleep_ms(5);

            //}
        }
        
        else if(numtype == 1)
        {
            itoa(currentvalue0, result, 2);
            /*for(int a = 0; a < numinputs; a++)
            {*/                
            if(((int)ceil(log10(currentvalue0)/log10(2))) > 13)
                {
                    result[(int)ceil(log10(currentvalue0)/log10(2))] = '\0';
                }
                else
                {
                    result[13] = '\0';
                }
                lcd_string(result);
                sleep_ms(5);
            //}
        }	
        
        else if(numtype == 2)
        {
            for(int b = numinputs; b < 0; b++)
            {
                temp = currentvalue0 / (16 ^ b);
                if(temp == 10)
                {
                    result[b] = 'A';
                }
                
                else if(temp == 11)
                {
                    result[b] = 'B';
                }
                
                else if(temp == 12)
                {
                    result[b] = 'C';
                }
                
                else if(temp == 13)
                {
                    result[b] = 'D';
                }
                
                else if(temp == 14)
                {
                    result[b] = 'E';
                }
                
                else if(temp == 15)
                {
                    result[b] = 'F';
                }
            }
                
            /*for(int a = 0; a < numinputs; a++)
            {*/
                if(((int)ceil(log10(currentvalue0)/log10(16))) > 13)
                {
                    result[(int)ceil(log10(currentvalue0)/log10(16))] = '\0';
                }
                else
                {
                    result[13] = '\0';
                }
                sleep_ms(5);
                lcd_string(result);
            //}
        }
    }

    else
    {
        for(int t = 0; t < currentvalue1; t++)
        {
            LED_FUNC(2000, 500);
        }
        if(numtype == 0)
        {
            itoa(currentvalue1, result1, 10);
            /*for(int a = 0; a < numinputs; a++)
            {*/

                
                lcd_string(result1);
                sleep_ms(1000);
                lcd_string(result);

            //}
        }
        
        else if(numtype == 1)
        {
            itoa(currentvalue1, result1, 2);
            /*for(int a = 0; a < numinputs; a++)
            {*/
                if(((int)ceil(log10(currentvalue1)/log10(2))) > 13)
                {
                    result1[(int)ceil(log10(currentvalue1)/log10(2))] = '\0';
                }
                else
                {
                    result1[13] = '\0';
                }
                lcd_string(result1);
                sleep_ms(5);
            //}
        }	
        
        else if(numtype == 2)
        {
            for(int b = numinputs-1; b > 0; b++)
            {
                temp = currentvalue1 / (16 ^ b);
                if(temp == 10)
                {
                    result1[b] = 'A';
                }
                
                else if(temp == 11)
                {
                    result1[b] = 'B';
                }
                
                else if(temp == 12)
                {
                    result1[b] = 'C';
                }
                
                else if(temp == 13)
                {
                    result1[b] = 'D';
                }
                
                else if(temp == 14)
                {
                    result1[b] = 'E';
                }
                
                else if(temp == 15)
                {
                    result1[b] = 'F';
                }
            }
                
            /*for(int a = 0; a < numinputs; a++)
            {*/
                if(((int)ceil(log10(currentvalue1)/log10(16))) > 13)
                {
                    result1[(int)ceil(log10(currentvalue1/log10(16)))] = '\0';
                }
                else
                {
                    result1[13] = '\0';
                }
                sleep_ms(5);
                lcd_string(result1);
            //}
        }
    }
	
	
}
		

void writevalue(char input[2])
{
    //lcd_string(input);
    //sleep_ms(1000);
	if(valuenumber == 0)
	{
		// if decimal mode and a decimal number
		if(numtype == 0 && input[0] >= 47 && input[0] <= 57)
		{
			currentvalue0 += atoi(input) * (10 ^ numinputs);
			value0[numinputs] = input[0];
			numinputs++;
		}
		
		// if binary and binary number
		else if(numtype == 1 && input[0] != '0' && input[0] != '1')
		{
			currentvalue0 += atoi(input) * (2 ^ numinputs);
			value0[numinputs] = input[0];
			numinputs++;
		}
		
		// if hex and hex number
		else if(numtype == 2 && ((input[0] >= 47 && input[0] <= 57) || (input[0] >= 65 && input[0] <= 70 )))
		{
			if(input[0] == 'A')
			{
				currentvalue0 = 10 * (16 ^ numinputs);
			}
			else if(input[0] == 'B')
			{
				currentvalue0 = 11 * (16 ^ numinputs);
			}
			else if(input[0] == 'C')
			{
				currentvalue0 = 12 * (16 ^ numinputs);
			}
			else if(input[0] == 'D')
			{
				currentvalue0 = 13 * (16 ^ numinputs);
			}
			else if(input[0] == 'E')
			{
				currentvalue0 = 14 * (16 ^ numinputs);
			}
			else if(input[0] == 'F')
			{
				currentvalue0 = 15 * (16 ^ numinputs);
			}
			value0[numinputs] = input[0];
			numinputs++;
			
		}
		value0[numinputs] = '\0';

	}
	else
	{
        
		// if decimal mode and a decimal number
        char var[20];
		if(numtype == 0 && input[0] >= 47 && input[0] <= 57)
		{
			currentvalue1 += atoi(input) * (10 ^ (numinputs-1));
			value1[(numinputs-1)] = input[0];
			numinputs++;
            itoa(numinputs, var, 10);
            lcd_string(var);
            sleep_ms(2000);
            //lcd_string(input);
            //sleep_ms(2000);
            //lcd_string(msg);
            //sleep_ms(2000);
		}
		
		// if binary and binary number
		else if(numtype == 1 && input[0] != '0' && input[0] != '1')
		{
			currentvalue1 += atoi(input) * (2 ^ (numinputs-1));
			value1[(numinputs-1)] = input[0];
			numinputs++;
		}
		
		// if hex and hex number
		else if(numtype == 2 && ((input[0] >= 47 && input[0] <= 57) || (input[0] >= 65 && input[0] <= 70 )))
		{
			if(input[0] == 'A')
			{
				currentvalue1 = 10 * (16 ^ (numinputs-1));
			}
			else if(input[0] == 'B')
			{
				currentvalue1 = 11 * (16 ^ (numinputs-1));
			}
			else if(input[0] == 'C')
			{
				currentvalue1 = 12 * (16 ^ (numinputs-1));
			}
			else if(input[0] == 'D')
			{
				currentvalue1 = 13 * (16 ^ (numinputs-1));
			}
			else if(input[0] == 'E')
			{
				currentvalue1 = 14 * (16 ^ (numinputs-1));
			}
			else if(input[0] == 'F')
			{
				currentvalue1 = 15 * (16 ^ (numinputs-1));
			}
			value1[(numinputs-1)] = input[0];
			numinputs++;
			
		}

        value1[(numinputs-1)] = '\0';
		
		
	}
	writetoLCD();

	
	return;
}

void LED_FUNC(int x,int y){

	gpio_put(LED_PIN, 1);
	sleep_ms(x);
	gpio_put(LED_PIN, 0);
	sleep_ms(y);
}


int main() {
#if !defined(i2c_default) || !defined(PICO_DEFAULT_I2C_SDA_PIN) || !defined(PICO_DEFAULT_I2C_SCL_PIN)
    #warning i2c/lcd_1602_i2c example requires a board with I2C pins
#else

    msg[0]='P';
    msg[1]='1';
    msg[2]='\0';



    char msg2[10];
    msg2[0] = '6';
    const uint LED_PIN = 25;
    gpio_init(LED_PIN);
    gpio_set_dir(LED_PIN, GPIO_OUT);
    LED_FUNC(1000,100);
    // This example will use I2C0 on the default SDA and SCL pins (4, 5 on a Pico)
	gpio_init(row1);
	gpio_init(row2);
	gpio_init(row3);
	gpio_init(row4);
	gpio_init(row5);
	
	gpio_init(col1);
	gpio_init(col2);
	gpio_init(col3);
	gpio_init(col4);
	gpio_init(col5);

    gpio_put(row2, true);
	gpio_put(row3, true);
	gpio_put(row4, true);
	gpio_put(row5, true);
	
	gpio_set_dir(row1, true);
	gpio_set_dir(row2, true);
	gpio_set_dir(row3, true);
	gpio_set_dir(row4, true);
	gpio_set_dir(row5, true);
	
	gpio_set_dir(col1, false);
	gpio_set_dir(col2, false);
	gpio_set_dir(col3, false);
	gpio_set_dir(col4, false);
	gpio_set_dir(col5, false);
	
	
	gpio_put(col1, false);
	gpio_put(col2, false);
	gpio_put(col3, false);
	gpio_put(col4, false);
	gpio_put(col5, false);
	
	

    // This example will use I2C0 on the default SDA and SCL pins (4, 5 on a Pico)
    i2c_init(i2c_default, 100 * 1000);
    gpio_set_function(PICO_DEFAULT_I2C_SDA_PIN, GPIO_FUNC_I2C);
    gpio_set_function(PICO_DEFAULT_I2C_SCL_PIN, GPIO_FUNC_I2C);
    gpio_pull_up(PICO_DEFAULT_I2C_SDA_PIN);
    gpio_pull_up(PICO_DEFAULT_I2C_SCL_PIN);
    // Make the I2C pins available to picotool
    bi_decl(bi_2pins_with_func(PICO_DEFAULT_I2C_SDA_PIN, PICO_DEFAULT_I2C_SCL_PIN, GPIO_FUNC_I2C));

    lcd_init(); //made it to here
    LED_FUNC(1000,100);
    static char *message[] =
            {
                    "RP2040 by", "Raspberry Pi",
                    "A brand new", "microcontroller",
                    "Twin core M0", "Full C SDK",
                    "More power in", "your product",
                    "More beans", "than Heinz! Lets add some shit"
            };

    lcd_string(msg);

    while (1) {
 
        gpio_put(row1, true);
	gpio_put(row2, true);
	gpio_put(row3, true);
	gpio_put(row4, true);
	gpio_put(row5, true);
	
	gpio_set_dir(row1, true);
	gpio_set_dir(row2, true);
	gpio_set_dir(row3, true);
	gpio_set_dir(row4, true);
	gpio_set_dir(row5, true);
	
	gpio_set_dir(col1, false);
	gpio_set_dir(col2, false);
	gpio_set_dir(col3, false);
	gpio_set_dir(col4, false);
	gpio_set_dir(col5, false);
	
	
	gpio_put(col1, false);
	gpio_put(col2, false);
	gpio_put(col3, false);
	gpio_put(col4, false);
	gpio_put(col5, false);

           while(gpio_get(col1) != 0 || gpio_get(col2) != 0 || gpio_get(col3) != 0 || gpio_get(col4) != 0 || gpio_get(col5) != 0)
		{
			sleep_ms(5);
            LED_FUNC(200,200);
		}

        //mew code
        /*
        sleep_ms(5);
		lcd_set_cursor(0,0);
		sleep_ms(5);
		lcd_send_byte(0b0000001100,LCD_COMMAND);
		sleep_ms(5); */

        //haveinput = 0;
		
  		while(haveinput == 0)
  		{
    			if(gpio_get(col1) != 0)
    			{
	      //change ROWS and COLUMNS 
				switchIO();
                sleep_us(10);
			      //Serial.print(digitalRead(col1));
			     
			      if(gpio_get(row1) != 0)
			      {
                    operation = '+';
				      valuenumber = 1;
                      numinputs = 0;
                      lcd_clear();
                      sleep_us(10);
                    
                   // LED_FUNC(100,100);
			       //Serial.print("row 1");
				/*Wire.beginTransmission(LCD_address);
				if(screen_on = 0)
				{
				  Wire.write(0b1000001100);
				}
				if(screen_on = 1)
				{
				  Wire.write(0b1000001000);
				}
				Wire.endTransmission();*/
			      }
			      else if(gpio_get(row2) != 0)
			      {
				//Serial.print("row 2");
				    writevalue("7");
                    sleep_us(10);
			//        Wire.beginTransmission(LCD_address);
			//        Wire.write(0b1000110001);
			//        Wire.endTransmission();
			      }

				else if(gpio_get(row3) != 0)
			      {
				//Serial.print("row 2");
				    writevalue("4");
                    sleep_us(10);
			//        Wire.beginTransmission(LCD_address);
			//        Wire.write(0b1000110001);
			//        Wire.endTransmission();
			      }
				else if(gpio_get(row4) != 0)
			      {
				//Serial.print("row 2");
				    writevalue("1");
                    sleep_us(10);
			//        Wire.beginTransmission(LCD_address);
			//        Wire.write(0b1000110001);
			//        Wire.endTransmission();
			      }
				else if(gpio_get(row5) != 0)
			      {
				//Serial.print("row 2");
				
				    writevalue("0");
                    sleep_us(10);
			//        Wire.beginTransmission(LCD_address);
			//        Wire.write(0b1000110001);
			//        Wire.endTransmission();
			      }
			      haveinput = 1;
			      break;
			    }
			
			
			    if(gpio_get(col2) != 0)
			    {
			      //change ROWS and COLUMNS 
			      switchIO();
			      //Serial.print("Column 2\n");
			      sleep_ms(5);
			      if(gpio_get(row1) != 0)
			      {
				//Serial.print("row 1");
				//writevalue(/*fill this with something */);
			//        Wire.beginTransmission(LCD_address);
			//        Wire.write(0b1000110010);
			//        Wire.endTransmission();
			      }
			      else if(gpio_get(row2) != 0)
			      {
				//Serial.print("row 2");
				    writevalue("8");
                    sleep_us(10);
			//        Wire.beginTransmission(LCD_address);
			//        Wire.write(0b1000110011);
			//        Wire.endTransmission();
			      }
				else if(gpio_get(row3) != 0)
			      {
				//Serial.print("row 2");
				    writevalue("5");
                    sleep_us(10);
			//        Wire.beginTransmission(LCD_address);
			//        Wire.write(0b1000110001);
			//        Wire.endTransmission();
			      }
				else if(gpio_get(row4) != 0)
			      {
				//Serial.print("row 2");
				   // writevalue('2');
                   operation = '+';
				      valuenumber = 1;
                      numinputs = 0;
                      sleep_us(10);
                      lcd_clear();
                      numinputs = 0;
                    
			//        Wire.beginTransmission(LCD_address);
			//        Wire.write(0b1000110001);
			//        Wire.endTransmission();
			      }
				else if(gpio_get(row5) != 0)
			      {
				//Serial.print("row 2");
				//writevalue(/*fill this with something */);
			//        Wire.beginTransmission(LCD_address);
			//        Wire.write(0b1000110001);
			//        Wire.endTransmission();
			      }

			      haveinput = 1;
			      break;
			    }
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

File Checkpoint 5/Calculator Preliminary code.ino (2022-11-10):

//Written by Angelo Maldonado-Liu
//10/28/2022
//PSU ECE 411
//
//
//
/* To do:
      assign values to each row/column pair
      for the equals sign, add in an LCD clear and then output the answer.
      Hex to Binary to Decimal converter.
      need to decide if i have say, 10 in the buffer, when I hit the convert button, does it become 0b1010, and then become 0xA, because if so, then I need to change the size of acceptable values, so that I can fit a D, B, H symbol to signify what type of values we are getting.
      */



#include <Wire.h>
#include <LiquidCrystal_I2C.h>

int row1 = ;
int row2 = ;
int row3 = ;
int row4 = ;
int row5 = ;
int col1 = ;
int col2 = ;
int col3 = ;
int col4 = ;
int col5 = ;

LiquidCrystal_I2C lcd(FIND THE LCD DISPLAY ADDRESS,20,4);  // set the LCD address to blank for a 20 chars and 4 line display (need to determine for our LCD)


char charOutput;
//variables needed for the math, max of 20 digits
char operation = '0';
char value0[18];
char value1[18];
char result[20];
int numType = 0;



int val# = 0;
int numCount;

//trash variable to hold things use with strtoul https://www.tutorialspoint.com/c_standard_library/c_function_strtoul.htm
char *garbage;

void setup() {
  Serial.begin(9600);
  // put your setup code here, to run once:
  //Here we put the button array gpio ports
  lcd.init();                      // initialize the lcd 
  lcd.init();
  // Print a message to the LCD.
  lcd.backlight();
  lcd.setCursor(1,0);




  //variables

}

void loop() {
  // put your main code here, to run repeatedly:
  
  //LCD gpio ports
  pinMode(row1, OUTPUT);
  pinMode(row2, OUTPUT);
  pinMode(row3, OUTPUT);
  pinMode(row4, OUTPUT);
  pinMode(row5, OUTPUT);
  pinMode(col1, INPUT);
  pinMode(col2, INPUT);
  pinMode(col3, INPUT);
  pinMode(col4, INPUT);
  pinMode(col5, INPUT);

  haveInput = 0;
  delay(50);
  if(val# == 1)
  {
    lcd.setCursor(2,1);
  }
  else
  {
    lcd.setCursor(1,0);
  }
  //check which button
  while(haveInput == 0)
  {
    if(digitalRead(col1) == 1)
    {
      //change ROWS and COLUMNS 
      switchIO();

      if(digitalRead(row1) == 1)
      {
        charOutput = ;
      }
      else if(digitalRead(row2) == 1)
      {
        charOutput = ;
      }
      else if(digitalRead(row3) == 1)
      {
        charOutput = ;
      }
      else if(digitalRead(row4) == 1)
      {
        charOutput = ;
      }
      else if(digitalRead(row5) == 1)
      {
        charOutput = ;
      }
      haveInput = 1;
    }
    if(digitalRead(col2) == 1)
    {
      //change ROWS and COLUMNS 
      switchIO();

      if(digitalRead(row1) == 1)
      {
        charOutput = ;
      }
      else if(digitalRead(row2) == 1)
      {
        charOutput = ;
      }
      else if(digitalRead(row3) == 1)
      {
        charOutput = ;
      }
      else if(digitalRead(row4) == 1)
      {
        charOutput = ;
      }
      else if(digitalRead(row5) == 1)
      {
        charOutput = ;
      }
      haveInput = 1;
    }

    if(digitalRead(col3) == 1)
    {
      //change ROWS and COLUMNS 
      switchIO();

      if(digitalRead(row1) == 1)
      {
        charOutput = ;
      }
      else if(digitalRead(row2) == 1)
      {
        charOutput = ;
      }
      else if(digitalRead(row3) == 1)
      {
        charOutput = ;
      }
      else if(digitalRead(row4) == 1)
      {
        charOutput = ;
      }
      else if(digitalRead(row5) == 1)
      {
        charOutput = ;
      }
      haveInput = 1;
    }

    if(digitalRead(col4) == 1)
    {
      //change ROWS and COLUMNS 
      switchIO();

      if(digitalRead(row1) == 1)
      {
        charOutput = ;
      }
      else if(digitalRead(row2) == 1)
      {
        charOutput = ;
      }
      else if(digitalRead(row3) == 1)
      {
        charOutput = ;
      }
      else if(digitalRead(row4) == 1)
      {
        charOutput = ;
      }
      else if(digitalRead(row5) == 1)
      {
        charOutput = ;
      }
      haveInput = 1;
    }

    if(digitalRead(col5) == 1)
    {
      //change ROWS and COLUMNS 
      switchIO();

      if(digitalRead(row1) == 1)
      {
        charOutput = ;
      }
      else if(digitalRead(row2) == 1)
      {
        charOutput = ;
      }
      else if(digitalRead(row3) == 1)
      {
        charOutput = ;
      }
      else if(digitalRead(row4) == 1)
      {
        charOutput = ;
      }
      else if(digitalRead(row5) == 1)
      {
        charOutput = ;
      }
      haveInput = 1;
    }
  }

  //write into the saved number values
  if(operation != '0')
  {
    lcd.setCursor(1,1);
    lcd.print(operation);
    val# = 1;
    return;
  }

  if(numType == 0)
  {
    if(val# == 0)
    {
      value0[numCount] = charOutput;
      numCount++;
      lcd.print(value0);
    }
    else if(val# == 1)
    {
      value1[numCount] = charOutput;
      numCount++;
      lcd.print(value1);
    }
  }
  else if(numType == 1)
  {
    if(val# == 0)
    {
      value0[numCount] = charOutput;
      numCount++;
      lcd.print(value0, BIN);
    }
    else if(val# == 1)
    {
      value1[numCount] = charOutput;
      numCount++;
      lcd.print(value1,BIN);
    }
  }

  else if(numType == 2)
  {
    if(val# == 0)
    {
      value0[numCount] = charOutput;
      numCount++;
      lcd.print(value0, HEX);
    }
    else if(val# == 1)
    {
      value1[numCount] = charOutput;
      numCount++;
      lcd.print(value1, HEX);
    }
  }



  
}

void switchIO() {
  pinMode(row1, INPUT);
  pinMode(row2, INPUT);
  pinMode(row3, INPUT);
  pinMode(row4, INPUT);
  pinMode(row5, INPUT);
  pinMode(col1, OUTPUT);
  pinMode(col2, OUTPUT);
  pinMode(col3, OUTPUT);
  pinMode(col4, OUTPUT);
  pinMode(col5, OUTPUT);
  return;
}

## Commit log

2022-10-07 Create BOM v1
2022-10-07 Create Schematic v1
2022-10-07 Rename Checkpoint 1-3/BOM v1 to Checkpoint 4/BOM v1
2022-10-07 Create Schematic v2
2022-10-07 Rename Checkpoint 4/Schematic v2 to Checkpoint 5/Schematic v2
2022-10-07 Rename Checkpoint 1-3/Schematic v1 to Checkpoint 4/Schematic v1
2022-10-07 Rename Schematic v2 to Final Schematic
2022-10-07 Rename Schematic v1 to Preliminary Schematic
2022-10-07 Create Actual Final Schematic
2022-10-07 Create Rough Schematic
2022-11-03 schematic update
2022-11-03 last mod
    [CAlculator.kicad_pcb, CAlculator.kicad_sch]
2022-11-10 updated i2c controller
    [CAlculator.kicad_pcb, CAlculator.kicad_sch]
2022-11-10 most pins connected except Vbus and ground
    Going to use ground plane so no need to connect ground pins yet
    [CAlculator.kicad_pcb, CAlculator.kicad_sch]
2022-11-11 Add files via upload
    Preliminary C code, as we are switching over to C
2022-11-17 final CAD
    board sent to FaB
    [CAlculator.kicad_pcb, CAlculator.kicad_sch]
2022-11-18 Rename calculator prototype code.ino to calculator prototyping code.ino
2022-11-27 change i2c default pins
    change the i2c pins from default values to GP14 and GP15
